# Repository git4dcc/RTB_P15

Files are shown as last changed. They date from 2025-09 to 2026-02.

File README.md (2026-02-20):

# RTB_P15





My homebrew P15 power board provides unmonitored power and is a stripped down version of the C11 power board. The main purpose of this card is to operate as a decoder tester/programmer via a USB connection to the PC. No external power supply is required as it can be powered via the USB and the optional isolated DC/DC converter.

<details>
<summary>See also</summary>

- [RTB_C10 - Master](/../../../../git4dcc/RTB_C10)
- [RTB_C11 - Power](/../../../../git4dcc/RTB_C11)
- [RTB_C12 - Booster](/../../../../git4dcc/RTB_C12)

</details>

<details>
<summary>User Guides</summary>

- User Guide - DE
- [User Guide - EN](https://rtb4dcc.de/rtb_user_guide_en/)

</details>

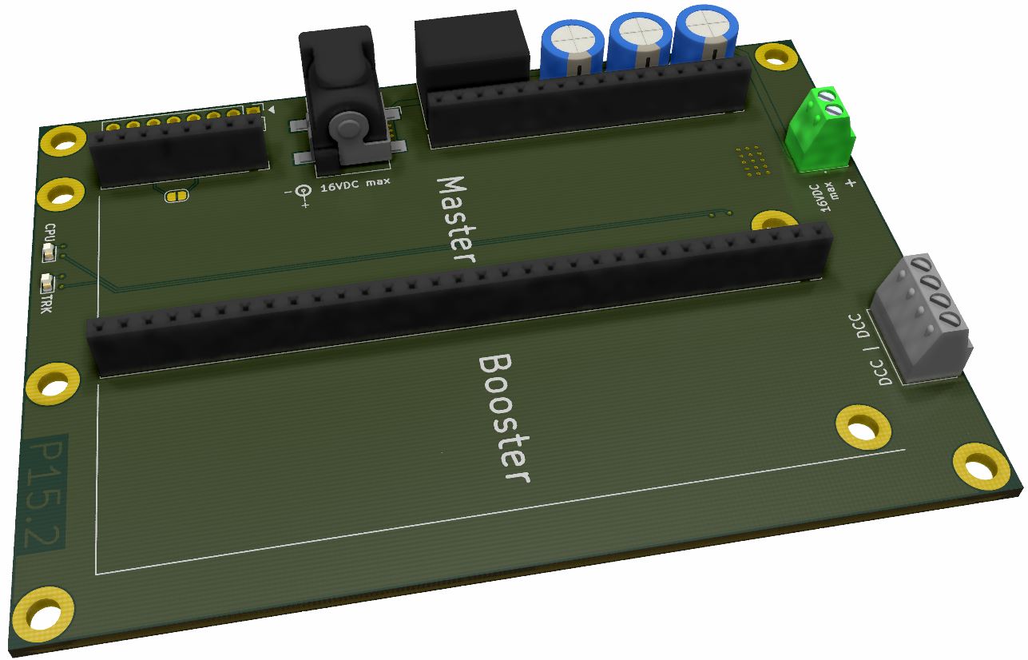
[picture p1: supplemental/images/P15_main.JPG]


## Power Board features
- **passive**
  - no CPU on this board
- **DC/DC**
  - isolated DC/DC step up converter (5V->12V, 250mA)
  - (optional) external power connect (12V-16V, >1A)
- **Slots**
  - 1x Master slot
  - 1x Booster slot
  - 1x FDX extender (for development only)
- **Connectors**
  - terminal connector or (2.1mm / 2.5mm) barrel jack for external power
  - DCC connector

# Hardware
The PCB layout uses SMD footprints down to 0603 parts. Handsoldering is possible.
Further, the PCB has been optimized for automated assembly (BOM and Position files as CSV).

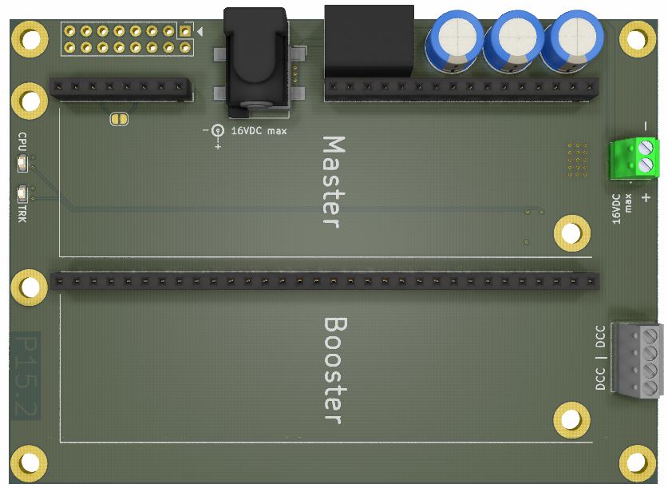
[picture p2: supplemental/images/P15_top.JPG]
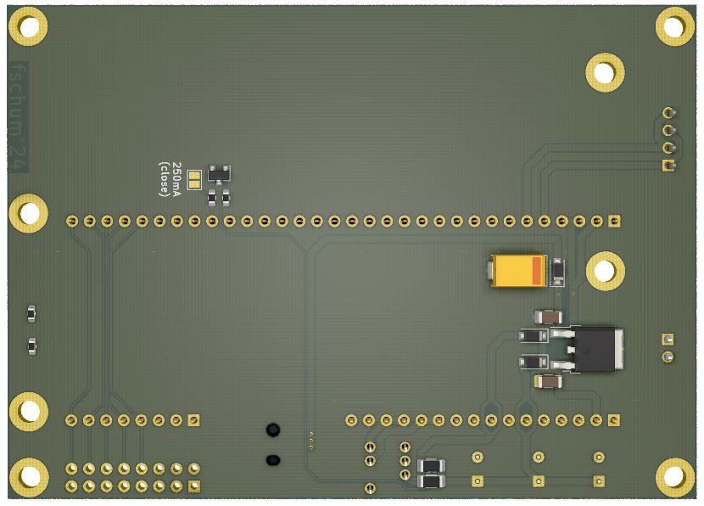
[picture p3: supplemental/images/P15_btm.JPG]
 

## PCB
- 2-layer PCB, FR4, 1.6mm
- CPU: none

# YouTube
See the (P15, C10, C12) used in the Decoder Tester use case.<br><br>
[](https://youtu.be/n1b2I9GNrNY)

This project is intended for hobby use only and is distributed in accordance with the Apache License 2.0 agreement.

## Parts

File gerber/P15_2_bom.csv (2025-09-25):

Designator | Footprint | Quantity | Value | LCSC Part #
C15 | CP_EIA-7343-43_Kemet-X | 1 | 47u/35V | C696814
C2, C3, C4 | CP_Radial_D8.0mm_P3.50mm | 3 | 680u/20V
C26 | 1206 | 1 | 22u/16V | C12891
C27 | 1206 | 1 | 2.2u/25V | C50254
D1, D2, D3 | D_SOD-123F | 3 | SS34F | C60396
D14 | 0603 | 1 | LED(ylw)
D25 | 0603 | 1 | LED(grn)
H1, H2, H3, H4, H5, H6, H8, H9 | MountingHole_3.2mm_M3_ISO7380_Pad | 8 | MountingHole
J1 | 1725656 | 1 | Screw_Terminal_01x02
J21 | PinHeader_2x08_P2.54mm_Vertical | 1 | Conn_01x16
J3 | PinSocket_1x32_P2.54mm_Vertical | 1 | Slot: Booster
J4 | PinSocket_1x08_P2.54mm_Vertical | 1 | Slot-a1
J5 | BarrelJack_CLIFF_FC681465S_SMT_Horizontal | 1 | Barrel_Jack_Switch
J6 | 1725672 | 1 | Screw_Terminal_01x04
J7 | PinSocket_1x16_P2.54mm_Vertical | 1 | Slot: Master
JP1 | SolderJumper-2_P1.3mm_Bridged_RoundedPad1.0x1.5mm | 1 | Jumper_2_Bridged
JP2 | SolderJumper-2_P1.3mm_Open_Pad1.0x1.5mm | 1 | 250mA fix
PS1 | TDN52412WI | 1 | TDN_5-0912WI
Q1 | SOT-23 | 1 | BC847 | C7420337
R1, R2 | 1206 | 2 | 100 | C17901
R3 | 0603 | 1 | 6.8k | C23212
R4 | 0603 | 1 | 2.7k | C13167
R89 | 0603 | 1 | 22k | C31850
R90 | 0603 | 1 | 10K | C25804
U5 | TO-252-2 | 1 | L78M12 | C22357875

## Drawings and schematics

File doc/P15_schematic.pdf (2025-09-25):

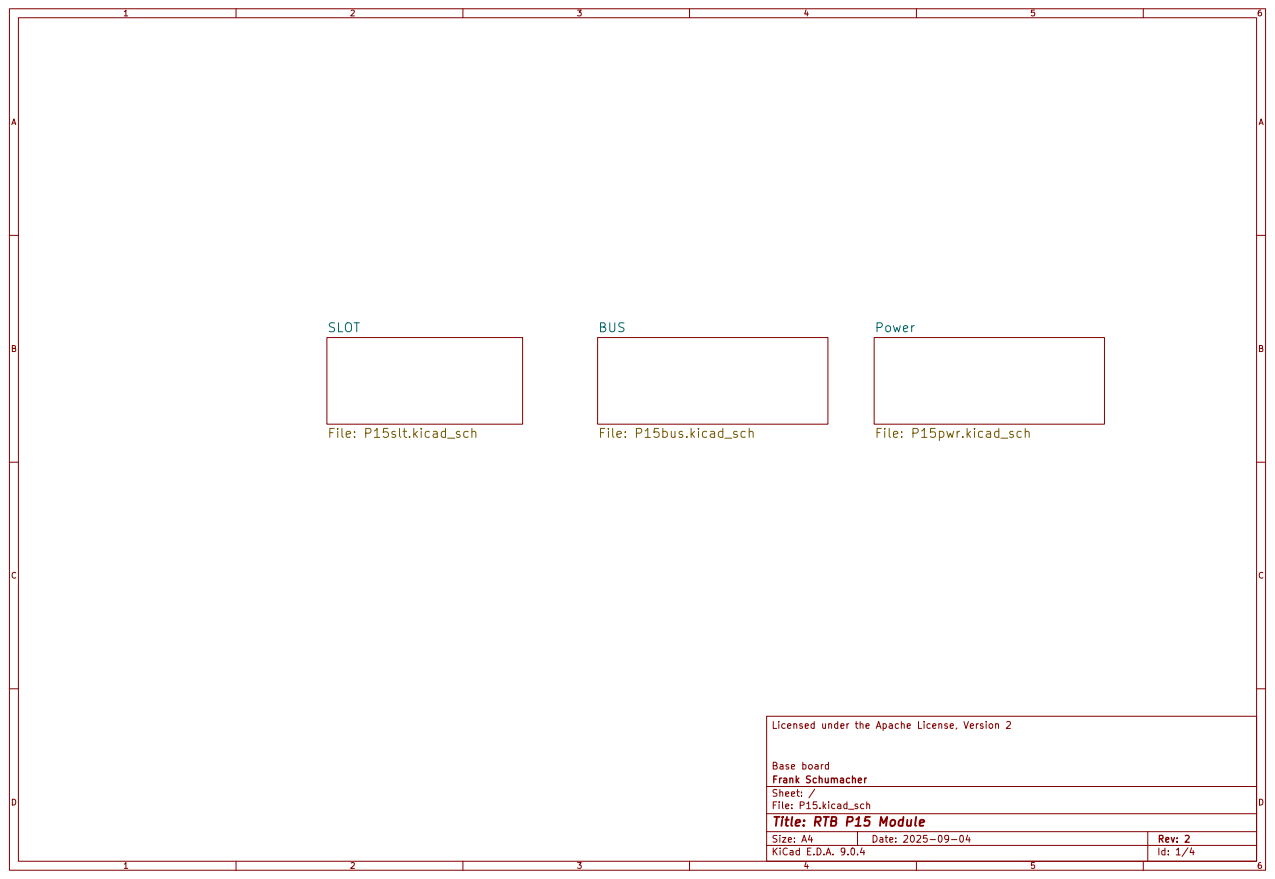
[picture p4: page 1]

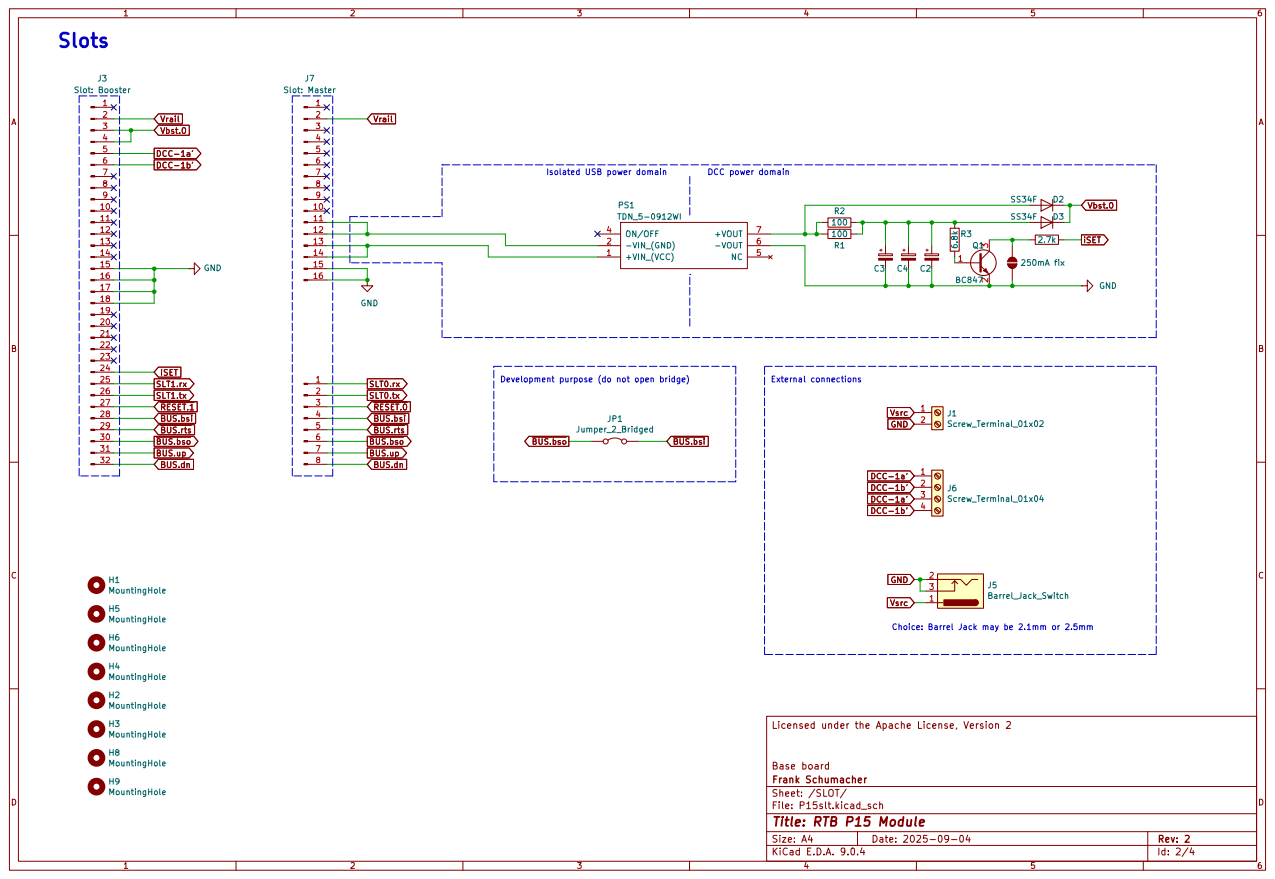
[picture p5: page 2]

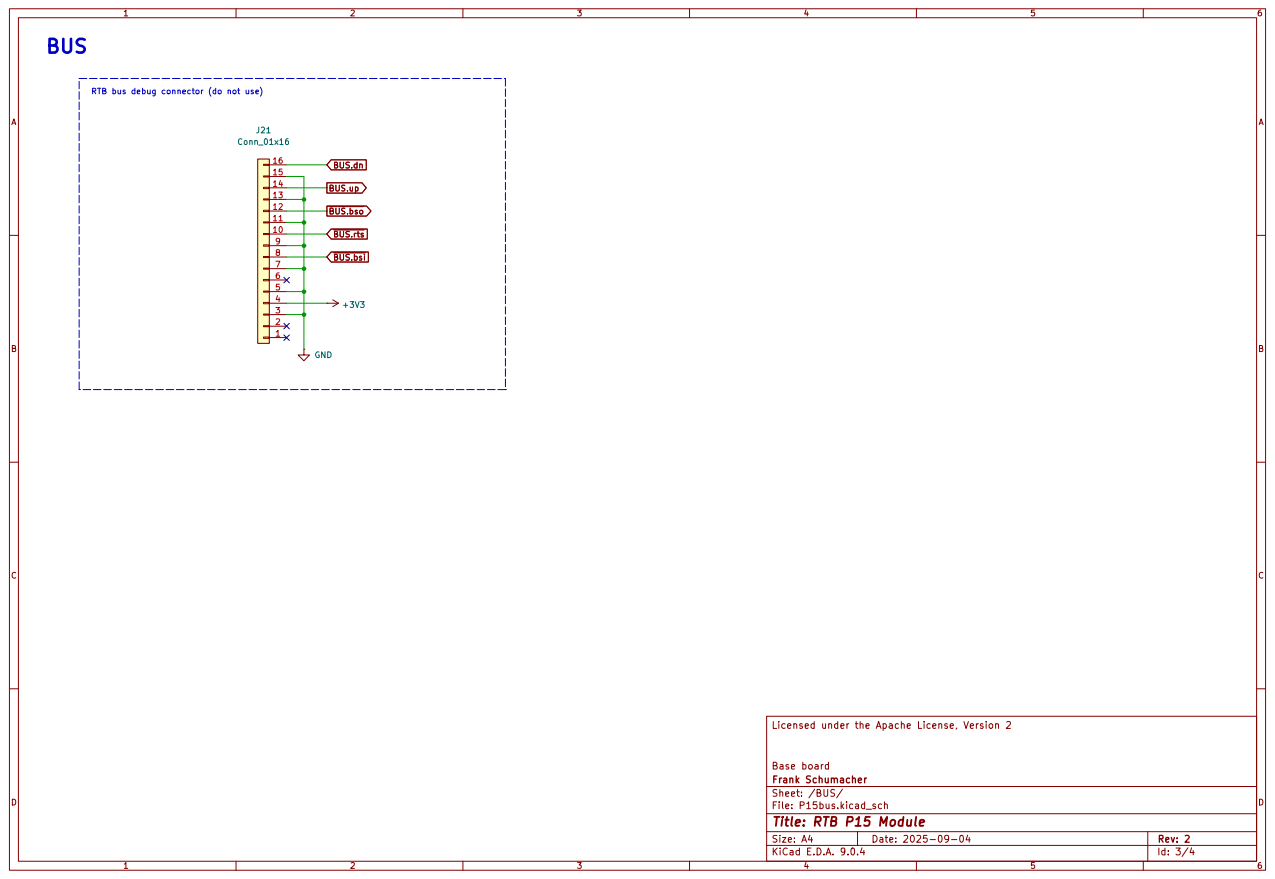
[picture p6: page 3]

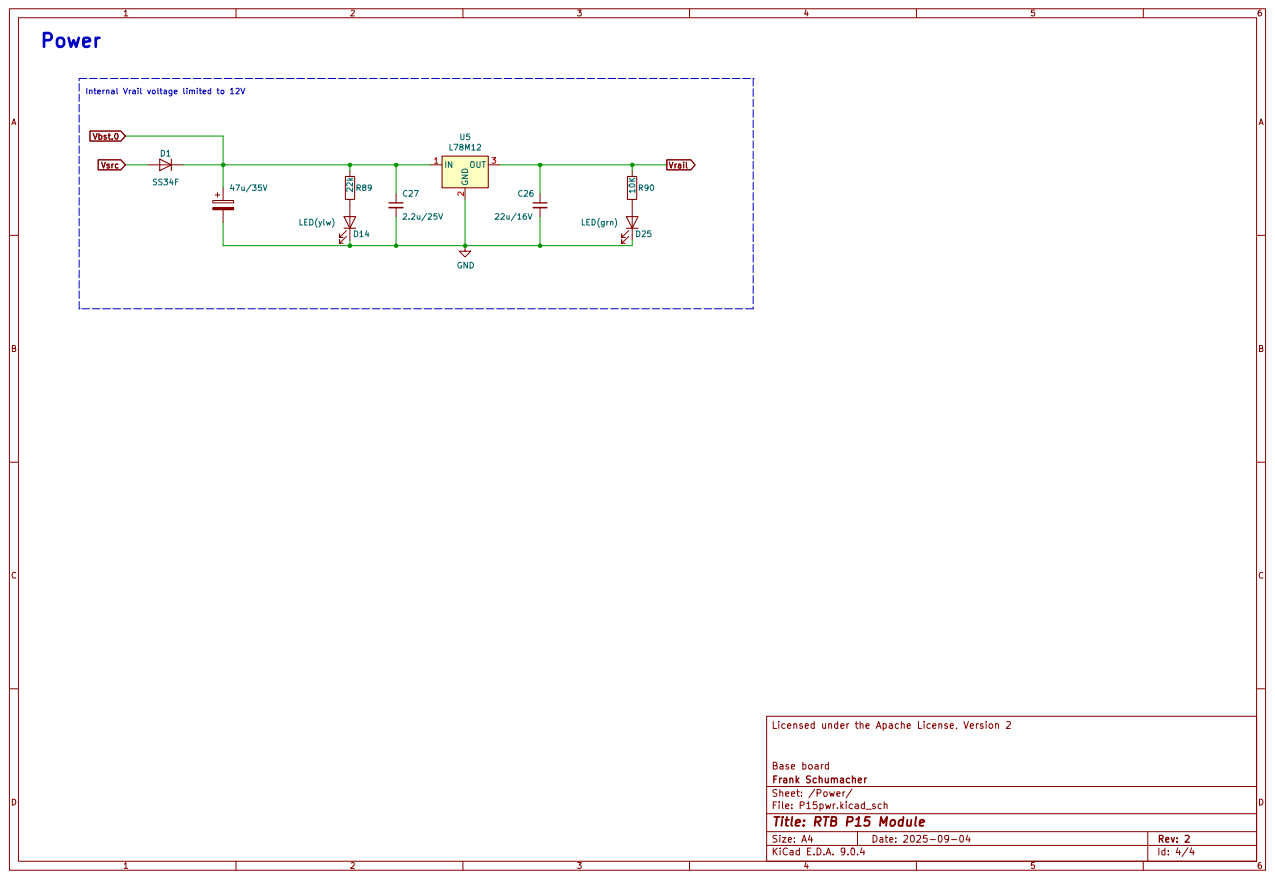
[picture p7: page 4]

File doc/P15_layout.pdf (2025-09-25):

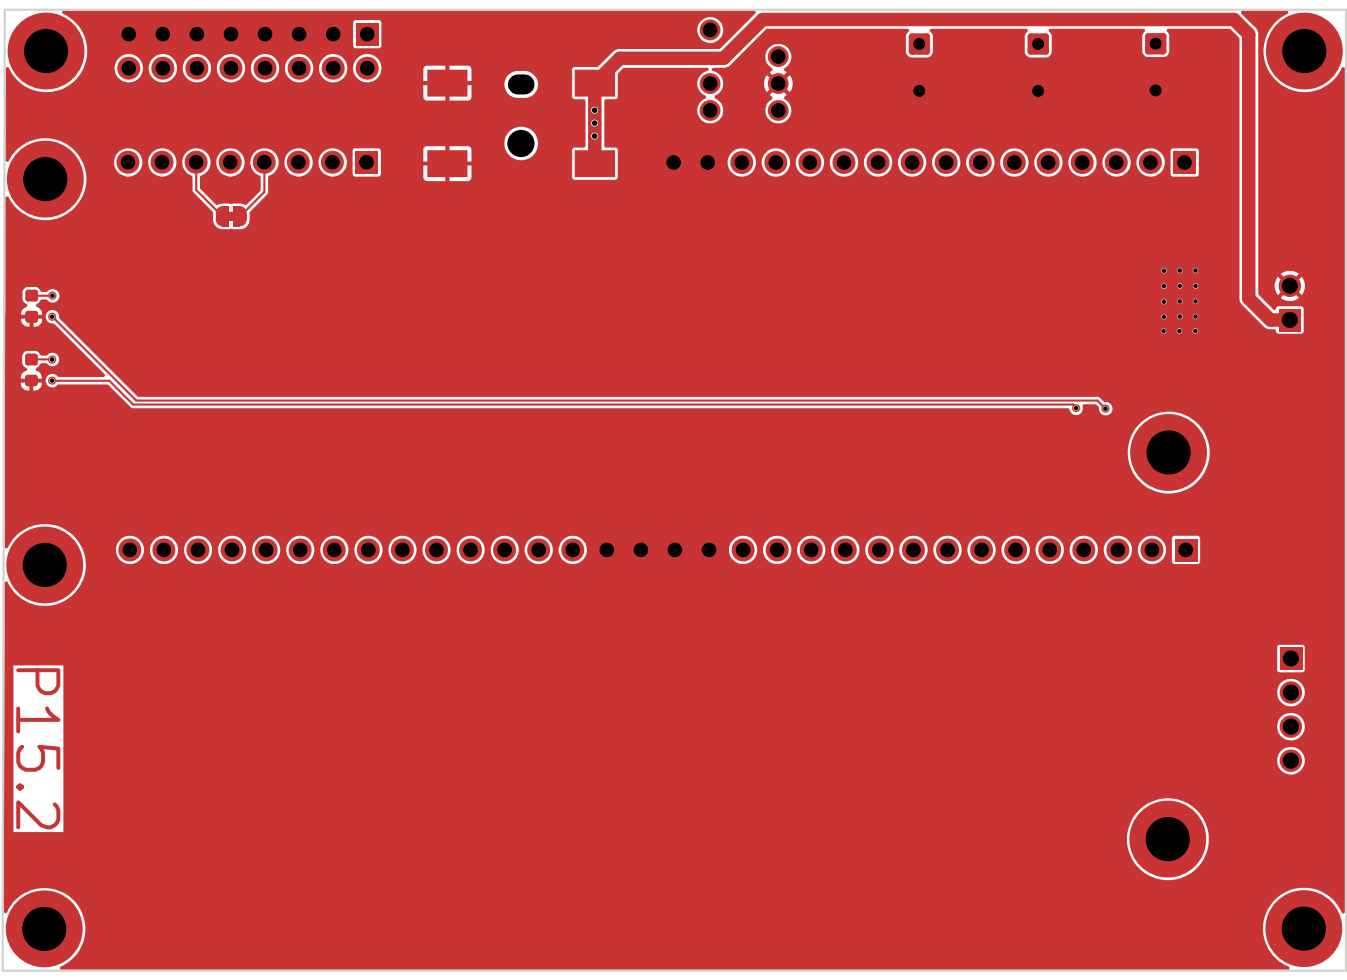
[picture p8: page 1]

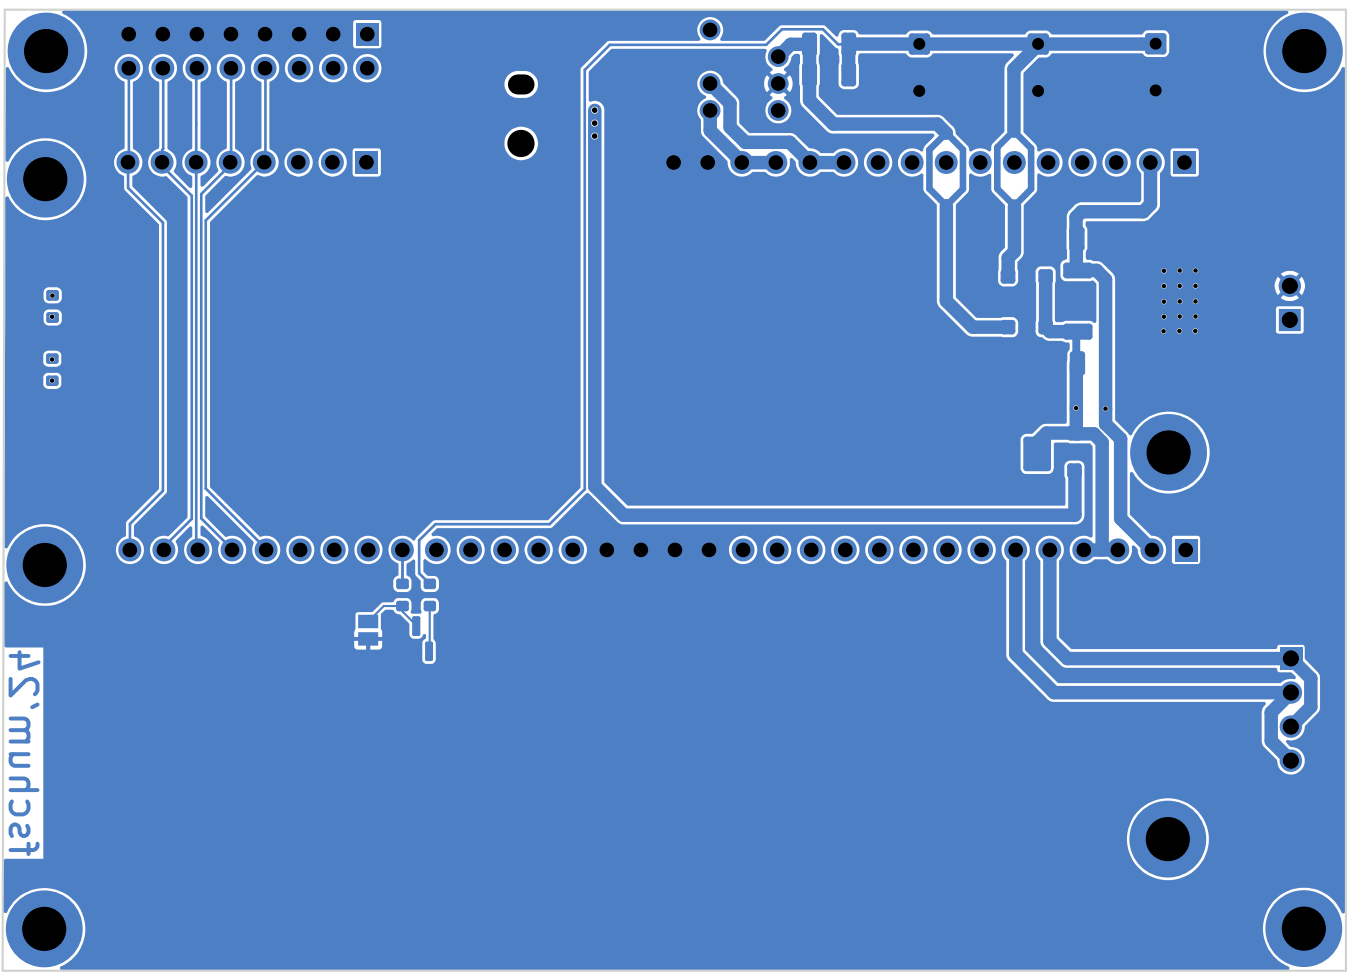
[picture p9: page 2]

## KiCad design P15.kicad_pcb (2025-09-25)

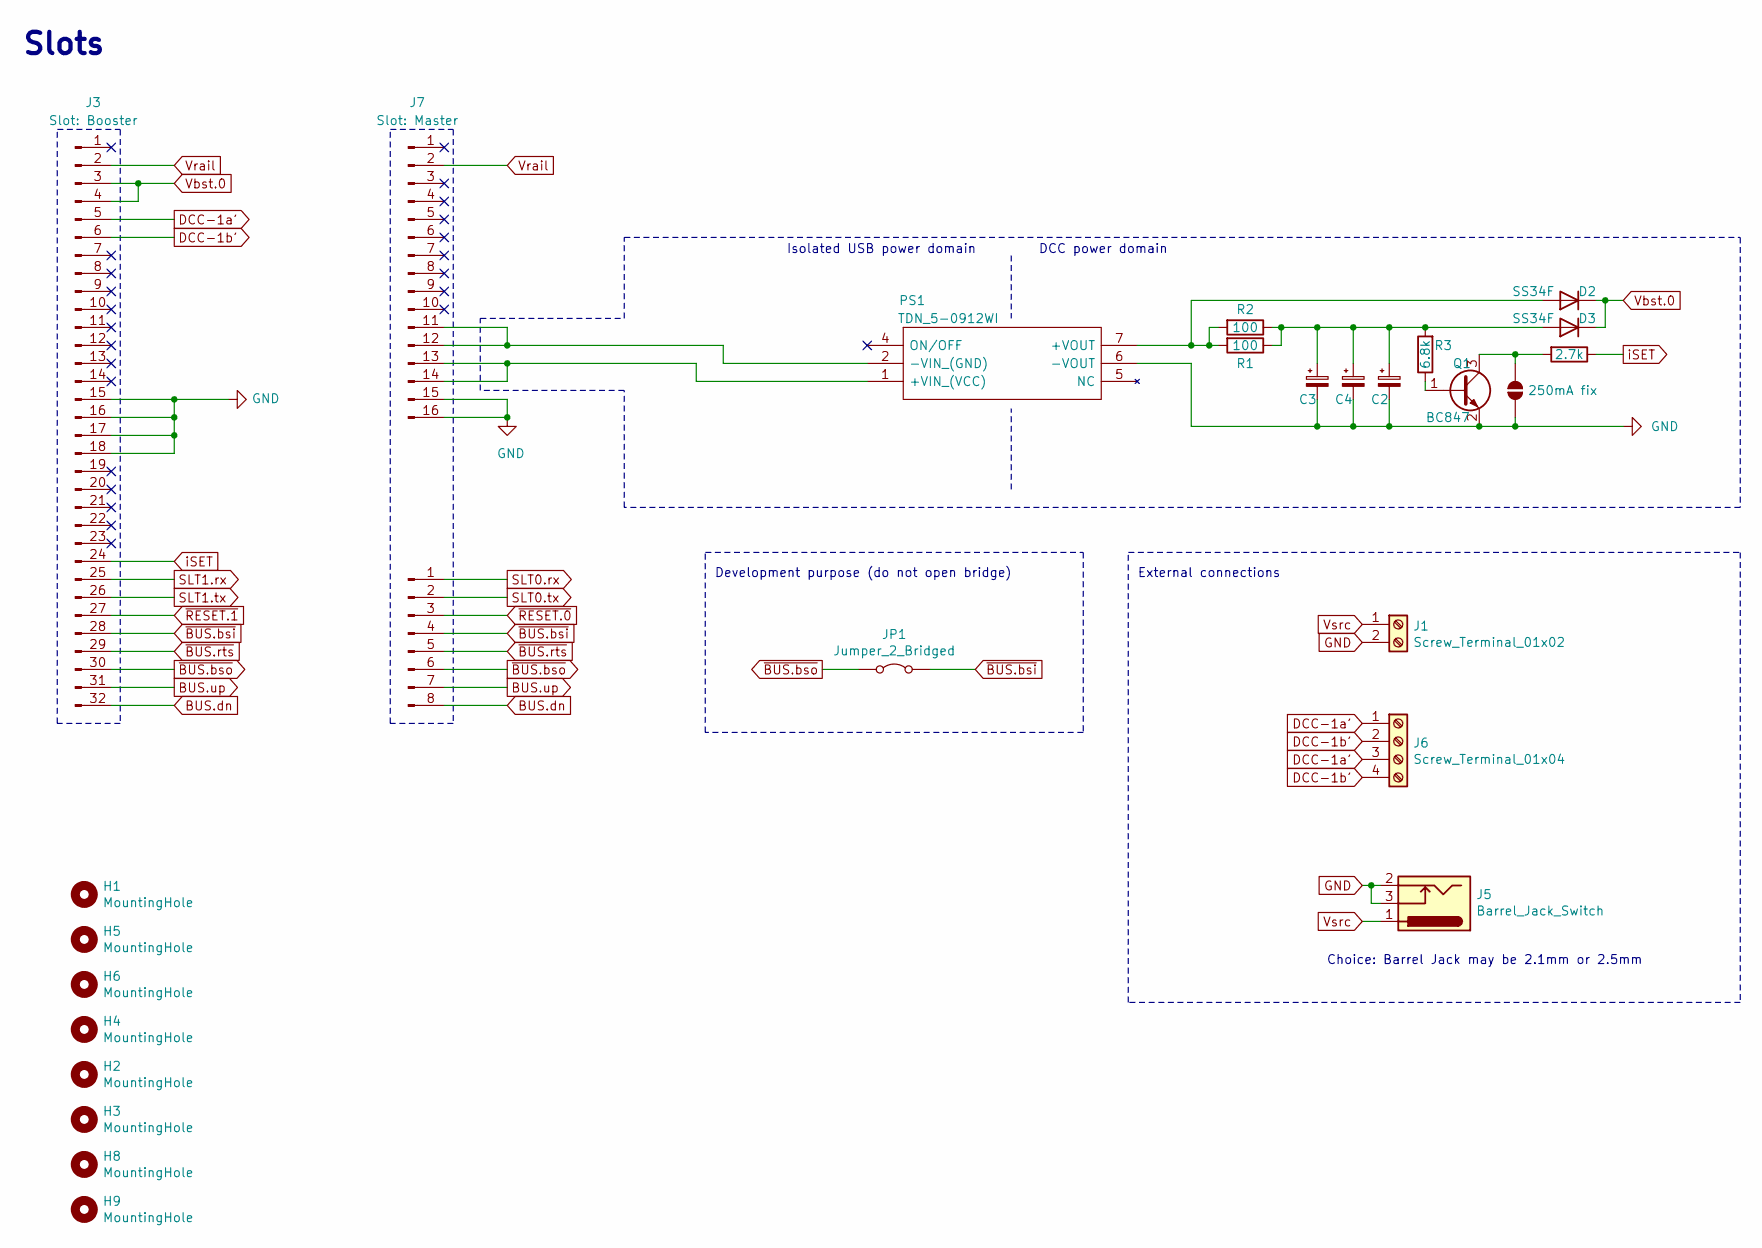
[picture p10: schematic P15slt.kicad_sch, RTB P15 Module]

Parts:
C2, C3, C4: 680u/20V; CP_Radial_D8.0mm_P3.50mm; Mouser 667-EEU-FR1E681L
D2, D3: SS34F; D_SOD-123F; LCSC Part # C60396
H1, H2, H3, H4, H5, H6, H8, H9: MountingHole; MountingHole_3.2mm_M3_ISO7380_Pad
J1: Screw_Terminal_01x02; 1725656
J3: Slot: Booster; PinSocket_1x32_P2.54mm_Vertical
J4: Slot-a1; PinSocket_1x08_P2.54mm_Vertical
J5: Barrel_Jack_Switch; BarrelJack_CLIFF_FC681465S_SMT_Horizontal; Mouser 163-0179-EX
J6: Screw_Terminal_01x04; 1725672
J7: Slot: Master; PinSocket_1x16_P2.54mm_Vertical
JP1: Jumper_2_Bridged; SolderJumper-2_P1.3mm_Bridged_RoundedPad1.0x1.5mm
JP2: 250mA fix; SolderJumper-2_P1.3mm_Open_Pad1.0x1.5mm
PS1: TDN_5-0912WI; TDN52412WI; Mouser 495-TDN5-0912WI
Q1: BC847; SOT-23; LCSC Part # C7420337
R1, R2: 100; R_1206_3216Metric; LCSC Part # C17901
R3: 6.8k; R_0603_1608Metric; LCSC Part # C23212
R4: 2.7k; R_0603_1608Metric; LCSC Part # C13167

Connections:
BUS.dn: J3.32, J4.8; also elsewhere on the board
BUS.up: J3.31, J4.7; also elsewhere on the board
DCC-1a': J3.5, J6.1, J6.3
DCC-1b': J3.6, J6.2, J6.4
GND: C2.2, C3.2, C4.2, J1.2, J3.15, J3.16, J3.17, J3.18, J5.2, J5.3, J7.15, J7.16, JP2.2 (B), PS1.6 (-VOUT), Q1.2 (E); also elsewhere on the board
unnamed: D2.2 (A), PS1.7 (+VOUT), R1.2, R2.2
unnamed: C2.1, C3.1, C4.1, D3.2 (A), R1.1, R2.1, R3.2
unnamed: J7.11, J7.12, PS1.2 (-VIN_(GND))
unnamed: J7.13, J7.14, PS1.1 (+VIN_(VCC))
unnamed: JP2.1 (A), Q1.3 (C), R4.2
unnamed: Q1.1 (B), R3.1
SLT0.rx: J4.1
SLT0.tx: J4.2
SLT1.rx: J3.25
SLT1.tx: J3.26
Vbst.0: D2.1 (K), D3.1 (K), J3.3, J3.4; also elsewhere on the board
Vrail: J3.2, J7.2; also elsewhere on the board
Vsrc: J1.1, J5.1; also elsewhere on the board
iSET: J3.24, R4.1
~BUS.bsi: J3.28, J4.4, JP1.2 (B); also elsewhere on the board
~BUS.bso: J3.30, J4.6, JP1.1 (A); also elsewhere on the board
~BUS.rts: J3.29, J4.5; also elsewhere on the board
~RESET.0: J4.3
~RESET.1: J3.27

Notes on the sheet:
Slots
Choice: Barrel Jack may be 2.1mm or 2.5mm
Isolated USB power domain
External connections
DCC power domain
Development purpose (do not open bridge)

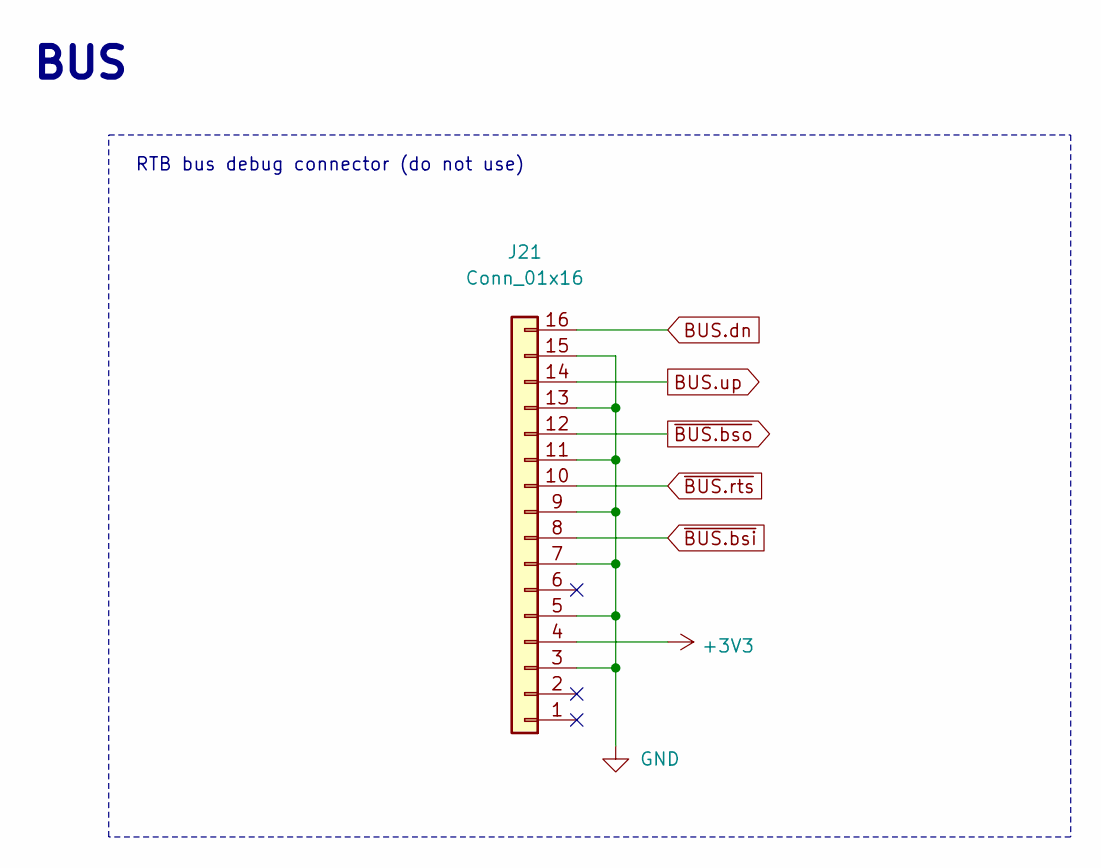
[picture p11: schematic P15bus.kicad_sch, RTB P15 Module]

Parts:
J21: Conn_01x16; PinHeader_2x08_P2.54mm_Vertical

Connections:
+3V3: J21.4
BUS.dn: J21.16; also elsewhere on the board
BUS.up: J21.14; also elsewhere on the board
GND: J21.3, J21.5, J21.7, J21.9, J21.11, J21.13, J21.15; also elsewhere on the board
~BUS.bsi: J21.8; also elsewhere on the board
~BUS.bso: J21.12; also elsewhere on the board
~BUS.rts: J21.10; also elsewhere on the board

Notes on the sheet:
RTB bus debug connector (do not use)
BUS

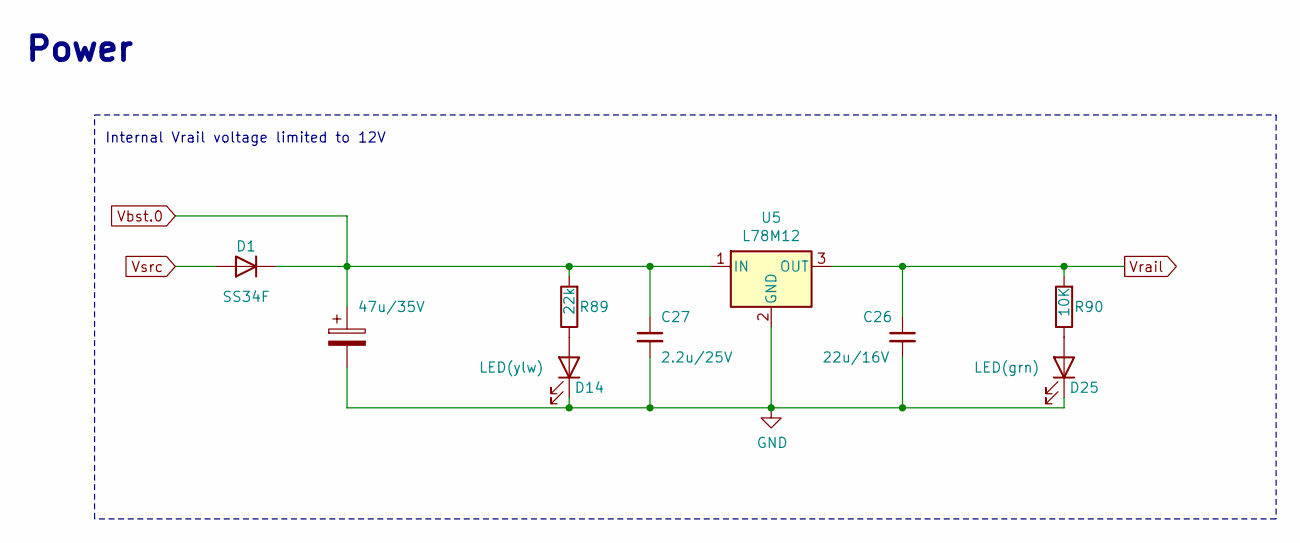
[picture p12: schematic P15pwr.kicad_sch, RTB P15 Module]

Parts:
C15: 47u/35V; CP_EIA-7343-43_Kemet-X; LCSC Part # C696814
C26: 22u/16V; C_1206_3216Metric; LCSC Part # C12891
C27: 2.2u/25V; C_1206_3216Metric; LCSC Part # C50254
D1: SS34F; D_SOD-123F; LCSC Part # C60396
D14: LED(ylw); LED_0603_1608Metric
D25: LED(grn); LED_0603_1608Metric
R89: 22k; R_0603_1608Metric; LCSC Part # C31850
R90: 10K; R_0603_1608Metric; LCSC Part # C25804
U5: L78M12; TO-252-2; LCSC Part # C22357875

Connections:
GND: C15.2, C26.2, C27.2, D14.1 (K), D25.1 (K), U5.2 (GND); also elsewhere on the board
unnamed: D14.2 (A), R89.1
unnamed: D25.2 (A), R90.1
Vbst.0: C15.1, C27.1, D1.1 (K), R89.2, U5.1 (IN); also elsewhere on the board
Vrail: C26.1, R90.2, U5.3 (OUT); also elsewhere on the board
Vsrc: D1.2 (A); also elsewhere on the board

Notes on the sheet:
Power
Internal Vrail voltage limited to 12V

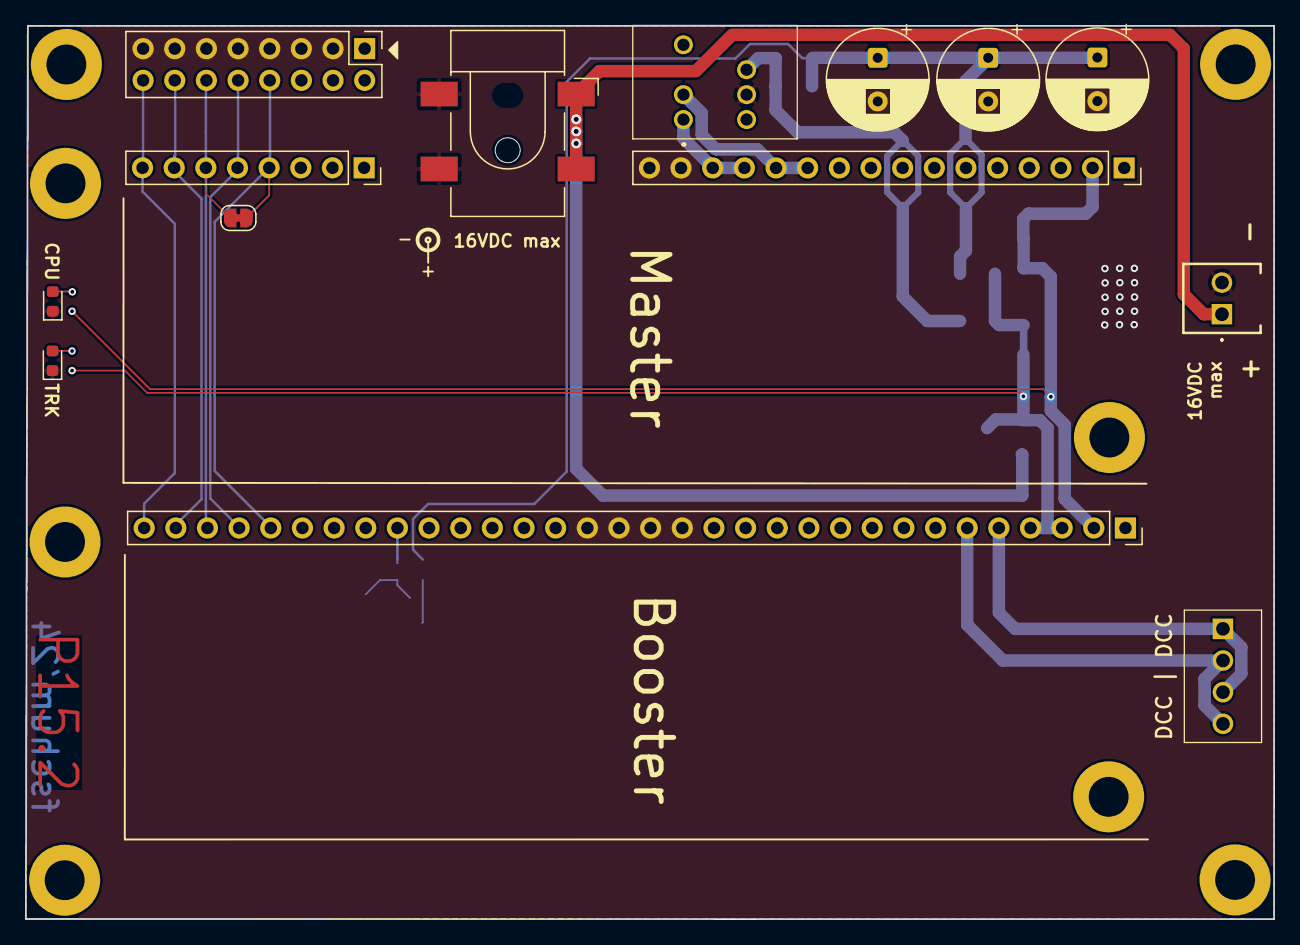
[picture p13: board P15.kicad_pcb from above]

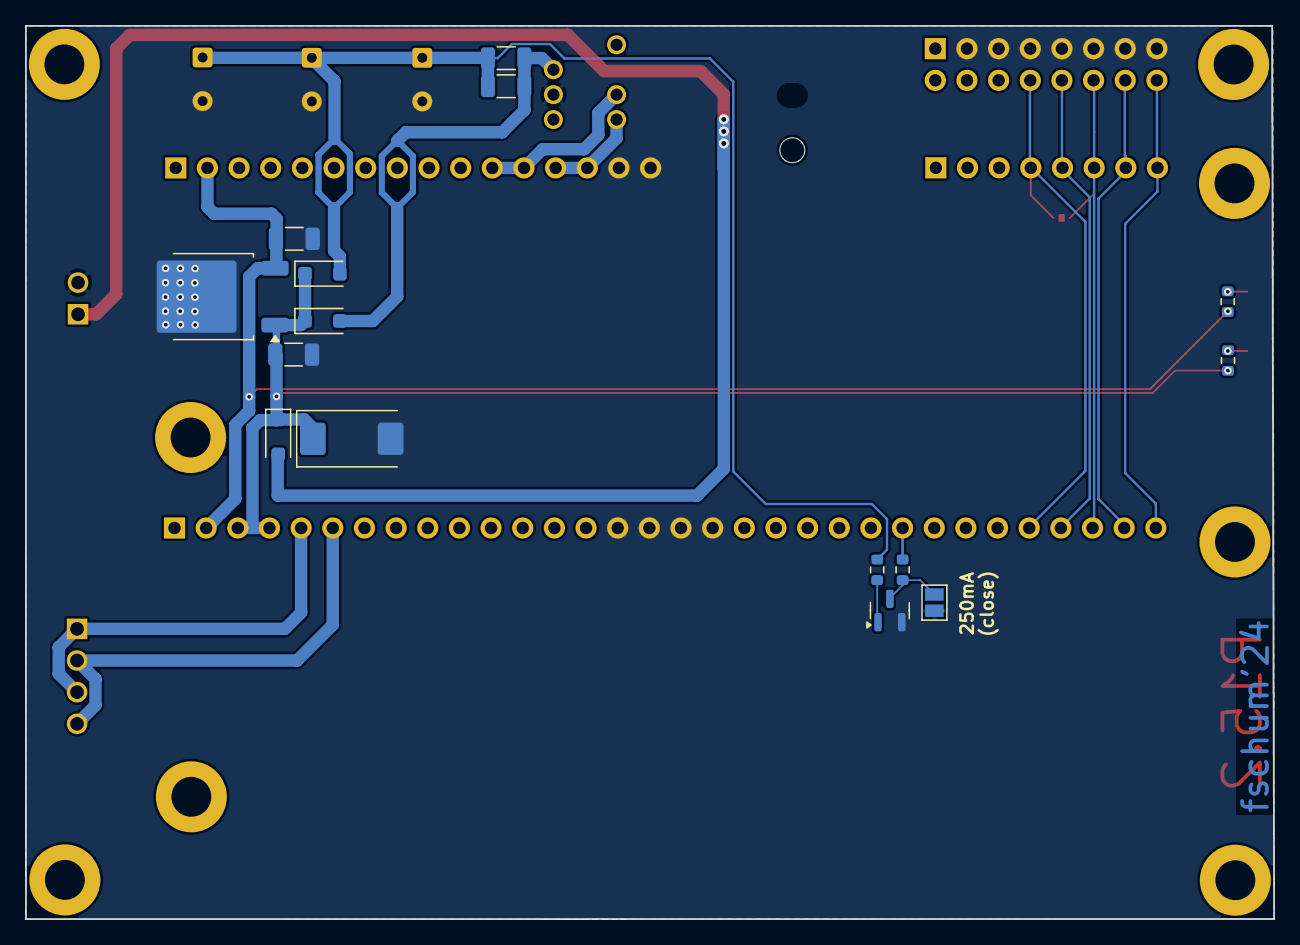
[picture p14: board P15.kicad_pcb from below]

Board: 2 copper layers, 100.2 x 71.7 mm, 37 parts (15 on the bottom side), 20 nets.

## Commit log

2025-09-04 mod: optimized for PCB assembly
    [P15.kicad_pcb, P15.sch, P15_2-bom.csv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]
2025-09-11 mod: corrected D2/D3 rotation
    [P15_2-btm-pos.csv]
2025-09-25 upgrade to Kicad 9
    [P15.kicad_pcb, P15.kicad_sch, P15.sch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]

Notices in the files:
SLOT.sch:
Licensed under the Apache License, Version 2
